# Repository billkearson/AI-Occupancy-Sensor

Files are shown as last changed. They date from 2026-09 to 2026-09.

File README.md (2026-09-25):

# AI Occupancy Sensor

An AI-compatible intelligent room occupancy sensor built around the FireBeetle 2 ESP32-C6, the DFRobot C4002 mmWave presence sensor, the ENS160 air-quality sensor, and the BME280 temperature/humidity/pressure sensor.

Primary program in this repo:

- `AI_Occupancy_Sensor.ino` (main Arduino sketch and active runtime)

`AI_Occupancy_Sensor.md` is the canonical architecture document for the AI Occupancy Sensor project.

## Technology stack

- Hardware: FireBeetle 2 ESP32-C6
- Sensors: DFRobot C4002 mmWave, ENS160, BME280
- Firmware: Arduino sketch in C++
- Connectivity: Wi‑Fi, MQTT, local HTTP server, MCP JSON-RPC over HTTP
- Integration: Home Assistant and Open WebUI via local MQTT/MCP exposure
- Enclosure: 3D-printed case with STL files in the [case](case) folder

## What the current firmware does

- Initializes the I2C bus and the C4002 UART link.
- Polls the C4002, ENS160, and BME280 sensors.
- Fuses the raw readings into a room context that tracks occupancy, motion, occupancy duration, and simple air-quality guidance.
- Runs with sensor degradation tolerance: ENS160 and BME280 failures are logged and tolerated, while the C4002 is required for the node to start.
- Keeps placeholder hooks for MQTT, HTTP, and MCP output so the runtime shape is in place while those interfaces are finished.

## Current code path

- [AI_Occupancy_Sensor.ino](AI_Occupancy_Sensor.ino) is the primary runtime and source of truth for behavior, MCP endpoints, and serial telemetry.
- The sketch owns the sensor polling, context inference, local config loading, and the MCP/HTTP integration points used by the node.

## Shared configuration

The project uses a single shared configuration header for local network and runtime settings: [config.h](config.h).

This file is the source of truth for:

- Wi‑Fi SSID and password
- NTP server list (`NTP_SERVERS`)
- Timezone selection (`TIMEZONE`)
- MQTT broker host, port, username, and password
- MQTT state and availability topic names
- MCP HTTP port (`MCP_HTTP_PORT`)

The Arduino sketch uses this file directly rather than redefining network settings in multiple places.

## Local configuration template

Create a local copy of [config.h.example](config.h.example) named `config.h` and replace each placeholder value before compiling:

- `WIFI_SSID`
- `WIFI_PASSWORD`
- `NTP_SERVERS`
- `TIMEZONE`
- `MCP_HTTP_PORT`
- `MQTT_BROKER_HOST`
- `MQTT_BROKER_PORT`
- `MQTT_USERNAME`
- `MQTT_PASSWORD`
- `MQTT_TOPIC_STATE`
- `MQTT_TOPIC_AVAILABILITY`
- `TEMP_OFFSET_F`
- `HUMIDITY_OFFSET_RH`

Keep the real `config.h` file local to your machine and do not commit credentials to source control.

## Sensor calibration offsets

The BME280 readings can be corrected in `config.h` using these optional offsets:

- `TEMP_OFFSET_F`: Temperature correction in Fahrenheit.
- `HUMIDITY_OFFSET_RH`: Relative humidity correction in RH percentage points.

Temperature offset is entered in Fahrenheit for convenience, then converted internally to Celsius before being applied to sensor values.

Examples:

- If the sensor reads 82.0F and a reference thermometer reads 79.5F, set `TEMP_OFFSET_F = -2.5f`.
- If the sensor reads 39% RH and a reference reads 42% RH, set `HUMIDITY_OFFSET_RH = 3.0f`.

Notes:

- Positive offsets increase reported values; negative offsets decrease them.
- Corrected humidity is clamped to the valid range of 0 to 100% RH.
- Offsets are applied in the current Arduino sketch and any future local port of the same logic.

## Hardware defaults

These defaults are defined in [config.h](config.h):

- Device name: `room-ai-node`
- C4002 UART TX: GPIO 16
- C4002 UART RX: GPIO 17
- C4002 baud rate: `115200`
- I2C SDA: GPIO 19
- I2C SCL: GPIO 20
- I2C clock: `400000`
- MCP HTTP port: `8081`
- MQTT broker host and Wi‑Fi credentials: blank placeholders for local configuration

## Wiring diagram

```mermaid
flowchart LR
    subgraph ESP[FireBeetle 2 ESP32-C6]
        direction TB
        VCC3[3V3]
        GND_TOP[GND]
        SDA[GPIO19 / SDA]
        SCL[GPIO20 / SCL]
        TX[GPIO16 / UART TX]
        RX[GPIO17 / UART RX]
        GND_BOTTOM[GND]
        VCC5[5V]
    end

    ENV[ENS160 + BME280
Combined Environmental Sensor
I²C: SDA / SCL / 3V3 / GND]
    C4002[C4002 mmWave Sensor
UART: RX / TX / GND
5V power tap]

    VCC3 -->|3V3| ENV
    GND_TOP -->|GND| ENV

    SDA -->|I²C SDA| ENV
    SCL -->|I²C SCL| ENV

    TX -->|ESP32 TX -> C4002 RX| C4002
    RX -->|ESP32 RX <- C4002 TX| C4002
    GND_BOTTOM -->|GND| C4002
    VCC5 -->|USB 5V tap| C4002
```

This is the current actual wiring used by the project: the ENS160 and BME280 share the same I²C bus, the C4002 uses the board UART, and the C4002 receives a dedicated 5V tap from the ESP32 USB rail for stable operation.

## Case fasteners

The 3D-printed enclosure uses the following hardware:

- Sensor mounting screws: M2 x 6 mm
- Sensor mounting screws: M2 x 8 mm
- Case assembly hex head bolts: M2 x 12 mm
- Case assembly threaded inserts: M2 x 4 x 3.5 mm

The M2 x 6 mm and M2 x 8 mm screws were used to attach the sensors to the case. The M2 x 12 mm hex head bolts and M2 x 4 x 3.5 mm threaded inserts were used to secure the case panels together.

## Power note for the C4002

The C4002 required more power than the ESP32 board could reliably supply through its GPIO header pins alone. In the current build, the sensor is powered from the ESP32 board's USB 5V rail via a red tap wire visible in the back-case photo. This is a deliberate external power feed for the sensor and is not provided through the ESP32's GPIO pin supply path.

The power tap is a practical hardware workaround to keep the C4002 stable while the ESP32 continues to operate as the controller and local intelligence node.

## Quick start

1. Install the Arduino core for the ESP32-C6 and select the correct board profile in Arduino IDE or VS Code.
2. Copy [config.h.example](config.h.example) to `config.h` and fill in your Wi‑Fi, MQTT, and MCP values.
3. Connect the ESP32-C6 via USB and compile/upload [AI_Occupancy_Sensor.ino](AI_Occupancy_Sensor.ino).
4. Open the serial monitor at 115200 baud to confirm startup logs and sensor readiness.
5. Test the local HTTP endpoints at `http://DEVICE_IP:8081/context` and `http://DEVICE_IP:8081/occupancy/history`, and the MCP endpoint at `http://DEVICE_IP:8081/mcp`.
6. Validate the MCP flow using [MCP-Test.ps1](MCP-Test.ps1) or the examples in [MCP-Testing.md](MCP-Testing.md).

## Troubleshooting

- No serial output: confirm the board profile is set to the ESP32-C6 and USB CDC is enabled.
- C4002 not responding: verify UART wiring and confirm the sensor is receiving stable power from the USB 5V rail as noted in the power section above.
- Wi‑Fi not connecting: verify SSID/password in [config.h](config.h) and check that the board is on the correct network.
- MCP requests failing: use POST with `Content-Type: application/json` and verify the JSON-RPC method names match the runtime implementation.
- Sensor values look wrong: check calibration offsets in [config.h](config.h) and confirm the board and sensor are still physically connected.

## Case build and Open WebUI validation

The repository includes current photos of the case, the printable STL enclosure files, and a screenshot showing live sensor data in Open WebUI.

3D case STL files:

- [case/Case3_front.stl](case/Case3_front.stl) — front panel shell
- [case/Case3_middle.stl](case/Case3_middle.stl) — middle body section
- [case/Case3_back.stl](case/Case3_back.stl) — rear enclosure panel

Case images:

- Front view:

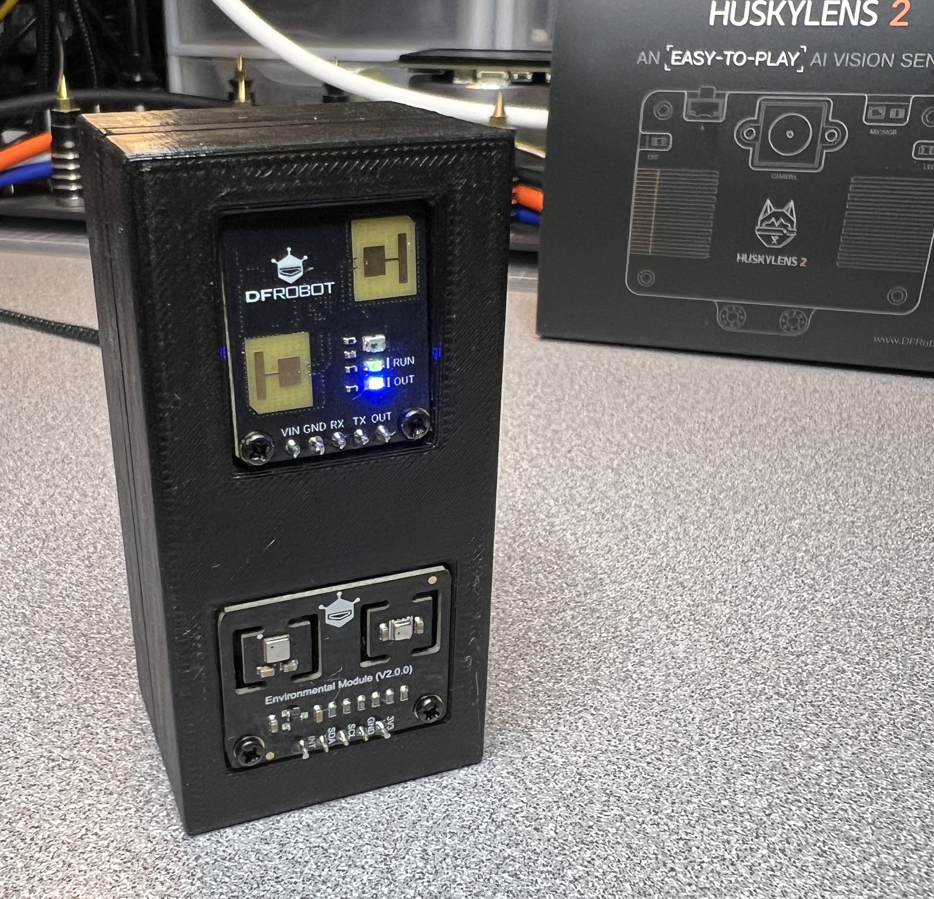
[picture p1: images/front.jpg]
Case front view
	

- Front view (alternate angle):

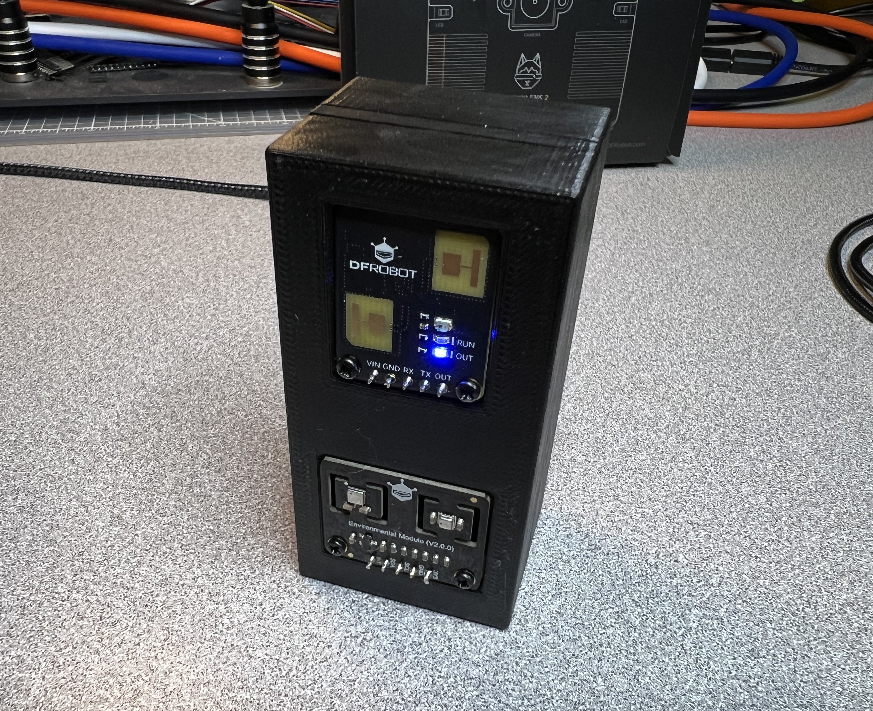
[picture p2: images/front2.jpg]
Alternate front view
	

- Back view:

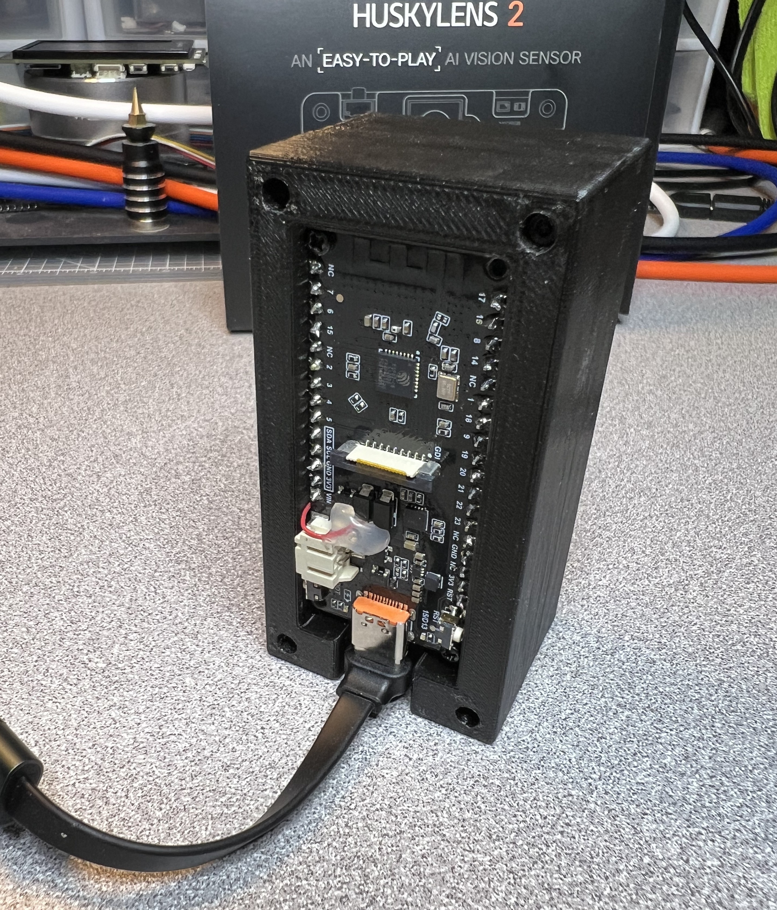
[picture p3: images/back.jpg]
Case back view
	

- Back view (alternate angle):

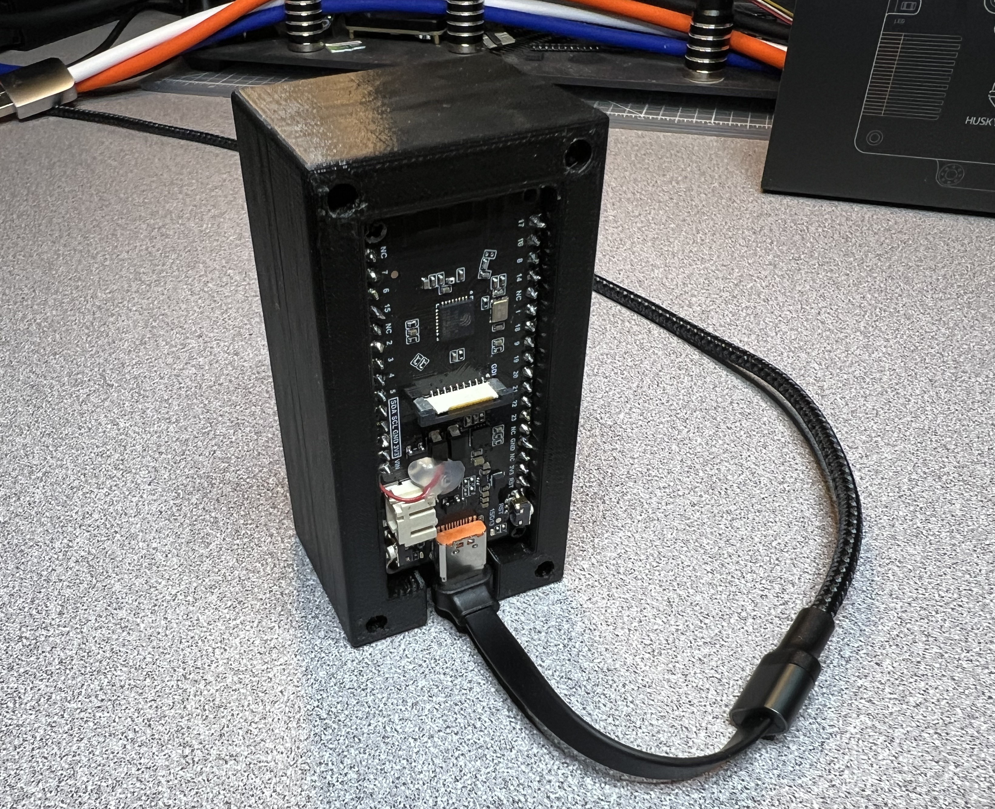
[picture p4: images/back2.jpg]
Alternate back view
	

- Parts and internal layout:

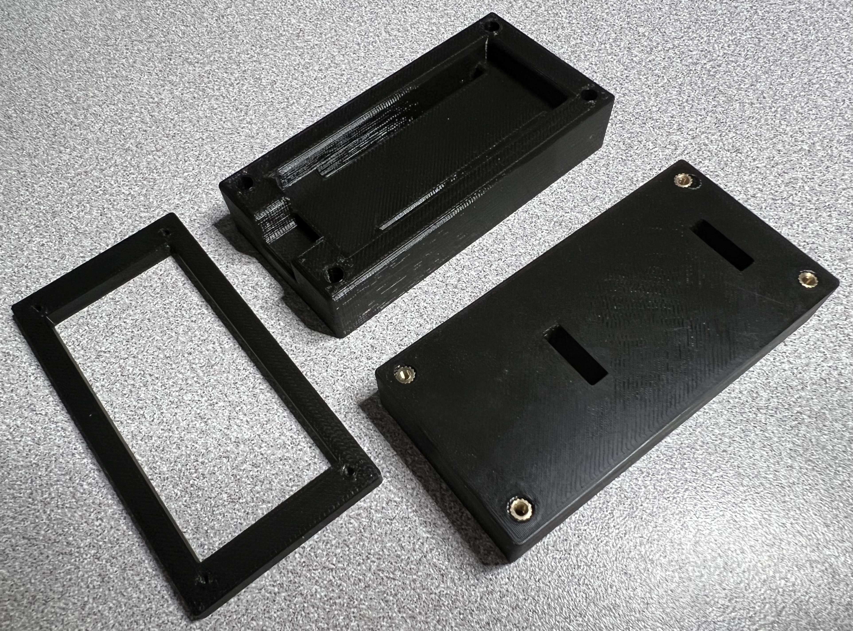
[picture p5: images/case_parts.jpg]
Case parts and internals
	

Open WebUI integration:

- Live sensor view in Open WebUI via MCP:

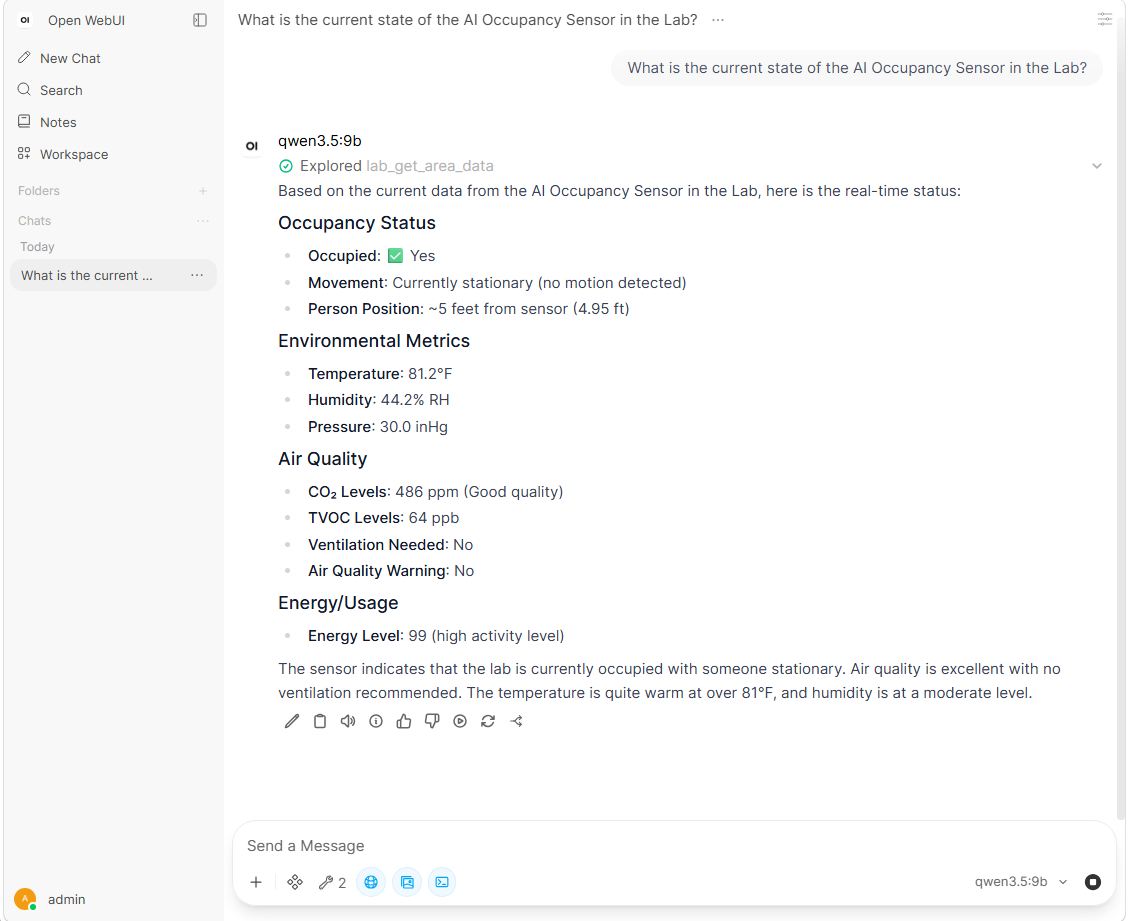
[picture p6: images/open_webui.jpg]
Open WebUI with sensor data
	

Home Assistant integration:

- Live sensor entities and state in Home Assistant:

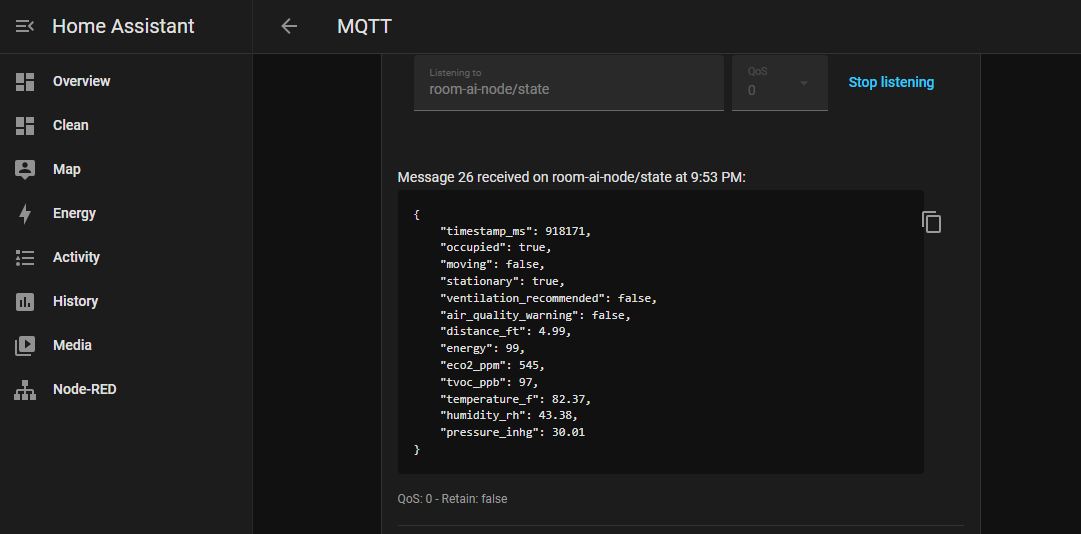
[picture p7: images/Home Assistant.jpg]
Home Assistant sensor view
	

## Console output

The `AI_Occupancy_Sensor.ino` sketch writes startup and loop logs to the serial console at `115200` baud. USB CDC on Boot must be enabled for the ESP32-C6 board profile, and on boards that expose USB CDC you should open the monitor before or immediately after reset so the startup banner is not missed.

Current runtime behavior in the sketch:

- C4002 is polled continuously in the main loop.
- Telemetry is published to serial every 5 seconds.
- Output is grouped with a sample header line.

Current sample format:

```text
--- sample 12 t=2026-09-24T19:51:32-0400 (ntp) ---
occupied=1 moving=0 stationary=1 vent=0
C4002 present=1 motion=0 static=1 dist=5.22ft energy=99
ENS160 ready=1 eco2=552 tvoc=101
BME280 ready=1 temp=82.67F humidity=41.10% pressure=30.04inHg
```

Field notes:

- `occupied`, `moving`, `stationary`, and `vent` are derived context-engine outputs.
- `t=` shows timezone-adjusted wall-clock time when NTP is available, otherwise uptime milliseconds.
- C4002 distance is displayed in feet (`ft`).
- BME280 temperature is displayed in Fahrenheit (`F`).
- BME280 pressure is displayed in inches of mercury (`inHg`).
- C4002 intensity is labeled `energy` (renamed from `activity`).

## Repo layout

- `AI_Occupancy_Sensor.ino` is the main Arduino program.
- `AI_Occupancy_Sensor.md` is the primary architecture and design document.
- `README.md` is the quick-start and operational guide.
- `config.h` and `config.h.example` hold the local network and runtime settings.

## MCP tool contract

Current MCP tool names advertised by tools/list in AI_Occupancy_Sensor.ino:

- get_area_data: Returns real-time environmental and occupancy metrics for the area.
- get_environmental_data: Returns temperature, humidity, and pressure metrics.
- get_occupancy_data: Returns presence, motion, static presence, distance, and energy.
- get_air_quality_data: Returns eCO2 and TVOC metrics.
- get_occupancy_history: Returns bounded occupancy transition history (depth 10).

Current MCP resources advertised by resources/list in AI_Occupancy_Sensor.ino:

- room://context/current: Current room context JSON.
- room://occupancy/history: Occupancy history JSON.

Timestamp contract:

- Payloads now expose `timestamp` (string) instead of `timestamp_ms`.
- When NTP is synced, `timestamp` is timezone-adjusted according to `TIMEZONE` in [config.h](config.h).
- When NTP is not synced, `timestamp` falls back to uptime text (for example, `12345ms`).

Occupancy history behavior:

- History is edge-only: entries are recorded only when `occupied` flips true/false.
- Maximum retained depth is 10 entries.

Tool name change note:

- Previous call names without the `get_` prefix were replaced with the `get_` prefixed names above.
- tools/list and tools/call must use the same canonical names.

MCP session limit note:

- The intended design target is 2 concurrent MCP sessions (`MAX_MCP_SESSIONS = 2`).
- The current Arduino sketch does not yet enforce a real session-cap tracking layer at runtime; this is a design target rather than a live runtime limit.

When tool names or descriptions change, align these locations:

- AI_Occupancy_Sensor.ino: tools/list tool metadata and tools/call routing checks.
- MCP-Test.ps1: JSON-RPC tools/call test payload names.
- MCP-Testing.md: expected tool list and tools/call request examples.
- AI_Occupancy_Sensor.md: MCP tool examples and architectural references.

## Acknowledgement

Special thanks to DFRobot for providing the hardware used in this project as part of their C4002 Free Trial Program.

Kit 3: Multi-Sensor Fusion Kit (Enabling richer environmental sensing)

Included hardware:

- FireBeetle 2 ESP32-C6 x 1 (DFR1075)
- Fermion C4002 mmWave Human Presence Sensor x 1 (SEN0691)
- Fermion ENS160 + BME280 Environmental Sensor x 1 (SEN0335)

## License

This project is licensed under the MIT License. See [LICENSE](LICENSE) for the full text.

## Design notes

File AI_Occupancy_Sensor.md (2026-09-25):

# AI Occupancy Sensor

## ESP32-C6 + C4002 + ENS160 + BME280

This document is the active architecture and reference document for the AI Occupancy Sensor project.

An AI-compatible intelligent room occupancy sensor in which the **FireBeetle 2 ESP32-C6 is the complete edge device**: sensor acquisition, context inference, MQTT integration, Home Assistant discovery, historical resources, and a minimal **MCP Streamable HTTP server** all run directly on the ESP32.

The design intentionally avoids a separate MCP gateway. Every MCP resource and tool is backed by data held by the ESP32.

## Technology stack

- Platform: FireBeetle 2 ESP32-C6
- Firmware: Arduino sketch written in C++
- Sensors: DFRobot C4002 mmWave, ENS160, BME280
- Connectivity: Wi‑Fi, MQTT, HTTP JSON endpoints, MCP Streamable HTTP
- Integration: Home Assistant and Open WebUI
- Enclosure: 3D-printed case using the STL files in the [case](case) folder

---

## 1. Project Goals

The system combines:

* **DFRobot C4002 mmWave Motion & Static Presence**
* **DFRobot ENS160 digital multi-gas sensor**
* **DFRobot BME280 temperature/humidity/pressure sensor**
* **DFRobot FireBeetle 2 ESP32-C6**

The finished node should answer questions such as:

> Is anyone in the room?

> How long has the room been occupied?

> Is the person moving or stationary?

> Is the environmental condition changing?

> Is air quality deteriorating while the room is occupied?

> What changed in the room during the last 30 minutes?

> Why did the system recommend ventilation?

The ESP32 performs deterministic edge inference and exposes the resulting state through:

1. **MQTT**
2. **Home Assistant MQTT Discovery**
3. **HTTP/JSON**
4. **MCP Streamable HTTP**

The architecture is deliberately **local-first**. No cloud service is required.

---

# 2. High-Level Architecture

```mermaid
flowchart LR
    ROOM[Room]

    C4002[C4002 mmWave
Presence + Motion]
    ENS[ENS160
Air quality]
    BME[BME280
Temperature / Humidity / Pressure]

    ESP[FireBeetle 2 ESP32-C6
Sensor Manager
Feature Engine
Context Engine
MQTT + HTTP + MCP]

    HA[Home Assistant]
    MCP[MCP Client / AI Agent]

    ROOM --> C4002
    ROOM --> ENS
    ROOM --> BME

    C4002 -->|UART| ESP
    ENS -->|I²C| ESP
    BME -->|I²C| ESP

    ESP -->|MQTT| HA
    ESP -->|HTTP / JSON| MCP
    ESP -->|MCP Streamable HTTP| MCP
```

The important architectural constraint is:

> **The ESP32 is the source of truth.**

Home Assistant and MCP clients consume the ESP32's state. They do not own the room's resources or intelligence.

---

# 3. Hardware

## 3.1 FireBeetle 2 ESP32-C6

The ESP32-C6 is the central controller.

The ESP32-C6 provides a 32-bit RISC-V processor, Wi-Fi 6, Bluetooth LE, and 802.15.4 connectivity. The current project is implemented as a single Arduino sketch running directly on the board, with the same device responsibilities handled in-code rather than by a separate ESP-IDF app structure.

---

## 3.2 C4002

The C4002 provides the occupancy-related information:

* static presence
* motion
* distance
* target information
* target energy/intensity
* direction where supported by the configured C4002 operating mode

The C4002 communicates with the ESP32 over UART.

### Power note for the C4002

The C4002 needed more power than the ESP32 could reliably provide through its GPIO pin supply path. In the physical build, the sensor is powered from the ESP32 board's USB 5V rail using a visible red tap wire, as seen in the back-case image. This red wire is a deliberate power feed from the board's USB connection and is not a GPIO-supplied power path.

This hardware arrangement was necessary to keep the C4002 stable while the ESP32 continued to act as the local controller, MQTT client, and MCP endpoint host.

---

## 3.3 ENS160

The ENS160 provides:

* TVOC
* eCO₂
* air-quality information

The ENS160 should be treated as an **air-quality/context sensor**, not as a precision CO₂ sensor.

The firmware and API should therefore use the field name:

```text
eco2_ppm
```

rather than:

```text
co2_ppm
```

---

## 3.4 BME280

The BME280 provides:

* temperature
* relative humidity
* atmospheric pressure

The BME280 and ENS160 share the I²C bus.

---

## 3.5 Case Build and Open WebUI Validation

The project now includes real build photos, printable enclosure STL files in the `case/` folder, and an Open WebUI screenshot under `images/`:

### Case hardware fasteners

The 3D-printed enclosure uses the following mounting hardware:

- Sensor mounting screws: M2 x 6 mm
- Sensor mounting screws: M2 x 8 mm
- Case assembly hex head bolts: M2 x 12 mm
- Case assembly threaded inserts: M2 x 4 x 3.5 mm

The M2 x 6 mm and M2 x 8 mm screws were used to attach the sensors to the case. The M2 x 12 mm hex head bolts and M2 x 4 x 3.5 mm threaded inserts were used to secure the case panels together.

### 3D printable case files

- [case/Case3_front.stl](case/Case3_front.stl)
- [case/Case3_middle.stl](case/Case3_middle.stl)
- [case/Case3_back.stl](case/Case3_back.stl)

### Case photos

Front view:

Case front view

Front view (alternate angle):

Alternate front view

Back view:

Case back view

Back view (alternate angle):

Alternate back view

Case parts and internals:

Case parts and internals

### Open WebUI integration screenshot

This screenshot shows the sensor exposed through MCP and consumed in Open WebUI:

Open WebUI with sensor data

### Home Assistant integration screenshot

This screenshot shows the sensor data exposed in Home Assistant:

Home Assistant sensor view

---

## Quick Start

1. Install the ESP32 Arduino board package and choose the FireBeetle 2 ESP32-C6 profile.
2. Copy [config.h.example](config.h.example) to a local [config.h](config.h) and populate Wi‑Fi, MQTT, and MCP settings.
3. Compile and upload [AI_Occupancy_Sensor.ino](AI_Occupancy_Sensor.ino) to the board.
4. Open the serial monitor at 115200 baud to confirm startup logs and sensor initialization.
5. Verify the local HTTP and MCP endpoints on the board's LAN address.
6. Run [MCP-Test.ps1](MCP-Test.ps1) or the examples in [MCP-Testing.md](MCP-Testing.md) to validate MCP behavior.

## Troubleshooting

- The board does not show startup logs: confirm the ESP32-C6 profile and serial monitor settings.
- The C4002 is unstable or silent: verify UART wiring and check the USB 5V power tap used for the sensor.
- MQTT or Wi‑Fi does not connect: review the shared configuration in [config.h](config.h).
- A request to `/context` or `/mcp` fails: confirm the endpoint is being called with the correct HTTP method and JSON-RPC payload.
- Values seem incorrect: check calibration and threshold settings in [config.h](config.h) before testing again.

---

# 4. Actual Wiring

This is the actual hardware wiring currently used in the project.

```mermaid
flowchart LR
    subgraph ESP[FireBeetle 2 ESP32-C6]
        direction TB
        VCC3[3V3]
        GND_TOP[GND]
        SDA[GPIO19 / SDA]
        SCL[GPIO20 / SCL]
        TX[GPIO16 / UART TX]
        RX[GPIO17 / UART RX]
        GND_BOTTOM[GND]
        VCC5[5V]
    end

    ENV[ENS160 + BME280
Combined Environmental Sensor
I²C: SDA / SCL / 3V3 / GND]
    C4002[C4002 mmWave Sensor
UART: RX / TX / GND
5V power tap]

    VCC3 -->|3V3| ENV
    GND_TOP -->|GND| ENV

    SDA -->|I²C SDA| ENV
    SCL -->|I²C SCL| ENV

    TX -->|ESP32 TX -> C4002 RX| C4002
    RX -->|ESP32 RX <- C4002 TX| C4002
    GND_BOTTOM -->|GND| C4002
    VCC5 -->|USB 5V tap| C4002
```

The board uses the FireBeetle 2 ESP32-C6 I²C pins `GPIO19` (SDA) and `GPIO20` (SCL). The default UART mapping for the C4002 is `GPIO16` as TX and `GPIO17` as RX. These values are defined in the firmware and kept in a single configuration location rather than being scattered across the code.

Network settings are centralized in the shared [config.h](config.h) file. This includes Wi‑Fi, MQTT broker details, and the MCP HTTP port so the project has a single source of truth instead of duplicate values in multiple files.

Time settings are also centralized in [config.h](config.h), including comma-delimited NTP servers (`NTP_SERVERS`) and timezone selection (`TIMEZONE`). If timezone parsing is unavailable, the runtime falls back to UTC.

## Acknowledgement

Special thanks to DFRobot for providing the hardware used in this project as part of their C4002 Free Trial Program, in Kit 3: Multi-Sensor Fusion Kit (Enabling richer environmental sensing).

Included hardware:

- FireBeetle 2 ESP32-C6 x 1 (DFR1075)
- Fermion C4002 mmWave Human Presence Sensor x 1 (SEN0691)
- Fermion ENS160 + BME280 Environmental Sensor x 1 (SEN0335)

## License

This project is licensed under the MIT License. See [LICENSE](LICENSE) for the full text.

The repository also includes [config.h.example](config.h.example), which is the template to copy locally as `config.h` and populate with your environment-specific values before building or flashing.

Verify the C4002 module's power and logic-level requirements before connecting it directly to 3.3 V GPIO.

---

# 5. Software Architecture

The primary runtime is the single-file Arduino sketch:

```text
AI_Occupancy_Sensor.ino
├── Configuration include
│   └── config.h
├── Sensor drivers (in-sketch classes)
│   ├── C4002Driver (UART occupancy/presence)
│   ├── Ens160Driver (I2C air quality)
│   └── Bme280Driver (I2C temperature/humidity/pressure)
├── Data models
│   ├── SensorSnapshot
│   └── RoomContext
├── Context inference
│   └── ContextEngine update and state tracking
├── Integrations
│   ├── MQTT publish and discovery payloads
│   ├── HTTP endpoints
│   └── MCP Streamable HTTP resources/tools
└── Main loop orchestration
  ├── Sensor polling
  ├── Context update
  ├── Telemetry/log output
  └── MCP/HTTP request handling
```

The current repository is intentionally Arduino-first and does not keep a separate ESP-IDF app tree as the active code path. The architecture remains modular in design, but the actual runtime is the single-file sketch that directly owns the sensor drivers, inference engine, and network integrations.

---

# 6. Runtime Tasks

Use FreeRTOS tasks to keep sensor acquisition independent from network activity.

```mermaid
flowchart TD
    ESP[ESP32-C6]

    C4002[C4002 Task
Radar state]
    ENV[Environment Task
Env state]
    NET[Network Task]

    FE[Feature Engine]
    CE[Context Engine]
    EE[Event Engine]
    MQTT[MQTT]
    HIST[History]
    HTTP[MCP / HTTP]

    ESP --> C4002
    ESP --> ENV
    ESP --> NET

    C4002 --> FE
    ENV --> FE
    FE --> CE
    CE --> EE

    EE --> MQTT
    EE --> HIST
    EE --> HTTP
```

Recommended starting rates:

| Function | Rate |
| --- | ---: |
| C4002 acquisition | 5–10 Hz |
| BME280 | 1 Hz |
| ENS160 | 1 Hz |
| Feature calculation | 1 Hz |
| Context engine | 1 Hz |
| MQTT telemetry |  1–5 seconds |
| MQTT state | On change |
| MCP state | On request |
| MCP events | Event-driven |

Current Arduino sketch behavior (`AI_Occupancy_Sensor.ino`) differs slightly for debug visibility:

- C4002 UART notifications are polled continuously.
- Combined telemetry is printed every 5 seconds.
- Sample `t=` prints timezone-adjusted wall-clock time when NTP is synced, otherwise uptime milliseconds.
- Console display uses feet (`ft`), Fahrenheit (`F`), and inches of mercury (`inHg`).

Current occupancy history behavior in the sketch:

- Depth is bounded to 10 entries.
- Entries are edge-only and recorded only when `occupied` flips true/false.

---

# 7. Canonical Room Observation

All sensor libraries should feed a normalized internal structure.

```cpp
struct RoomObservation {
  const char* timestamp;
  bool time_source_ntp;

    // Environment
    float temperature_c;
    float humidity_pct;
    float pressure_hpa;

    // Air quality
    uint16_t tvoc_ppb;
    uint16_t eco2_ppm;
    uint8_t aqi;

    // Radar
    bool presence;
    bool motion;
    float target_distance_m;
    uint8_t target_energy;
    float target_speed;
    int8_t target_direction;
    uint8_t target_count;

    // Radar/environment information
    float light_level;

    // Derived values
    float activity_score;
    float presence_confidence;
    float temperature_trend;
    float humidity_trend;
    float eco2_trend;
    float tvoc_trend;
};
```

Everything else should derive from this structure.

---

# 8. Feature Engine

Raw sensor values are converted into temporal features.

```text
presence_duration
absence_duration
motion_rate
stationary_duration

temperature_delta_5m
humidity_delta_5m

eco2_delta_5m
tvoc_delta_5m

activity_score
presence_confidence

air_quality_trend
environmental_anomaly_score
```

The system should maintain short rolling windows rather than storing every raw sample indefinitely.

Suggested windows:

```text
10 seconds
1 minute
5 minutes
15 minutes
1 hour
24 hours
```

---

# 9. Context Engine

The first version should use a deterministic state machine.

Do **not** make an LLM responsible for basic occupancy inference.

```text
                 ┌─────────────┐
                 │    EMPTY    │
                 └──────┬──────┘
                        │
                    presence
                        │
                        ▼
                 ┌─────────────┐
                 │  OCCUPIED   │
                 └──────┬──────┘
                        │
             ┌──────────┼──────────┐
             │          │          │
             ▼          ▼          ▼
          ACTIVE     STATIONARY  TRANSITION
             │          │
             │          ▼
             │     LONG_STATIONARY
             │          │
             └────┬─────┘
                  ▼
            ENVIRONMENTAL
               CONTEXT
```

Initial states:

```text
EMPTY
OCCUPIED
ACTIVE
STATIONARY
LONG_STATIONARY
AIR_DEGRADING
HOT
HUMID
VENTILATION_RECOMMENDED
ENVIRONMENTAL_ANOMALY
```

---

# 10. Confidence Rather Than Absolute Claims

The system should never pretend that the sensors know more than they actually do.

Use:

```json
{
  "state": "stationary",
  "confidence": 0.91
}
```

rather than:

```json
{
  "person_is_working": true
}
```

Higher-level interpretations can be represented as hypotheses:

```json
{
  "context": "work_like_stationary_activity",
  "confidence": 0.78
}
```

The distinction is important because mmWave presence plus environmental measurements cannot reliably determine a person's exact activity.

---

# 11. Canonical Room State

The ESP32 maintains one current room state.

```json
{
  "schema": "roomai.v1",

  "device": {
    "id": "roomai-01",
    "room": "office",
    "firmware": "0.1.0"
  },

  "presence": {
    "present": true,
    "confidence": 0.97,
    "duration_s": 4230,
    "motion": false,
    "distance_m": 2.14
  },

  "activity": {
    "state": "stationary",
    "score": 0.17,
    "confidence": 0.88
  },

  "environment": {
    "temperature_c": 24.3,
    "humidity_pct": 48.2,
    "pressure_hpa": 1014.1
  },

  "air": {
    "eco2_ppm": 812,
    "tvoc_ppb": 193,
    "aqi": 1
  },

  "context": {
    "room_state": "occupied",
    "air_state": "good",
    "ventilation_recommended": false
  }
}
```

This structure is the foundation for MQTT, Home Assistant, HTTP, and MCP.

---

# 12. Local History

Because **all resources must live on the ESP32**, the device needs a local history mechanism.

Do not attempt to retain every high-frequency sensor reading forever.

Instead, maintain:

### Short-term raw history

```text
10 Hz radar-derived observations
approximately 1–5 minutes
```

### 1-second/1-minute aggregates

```text
temperature
humidity
pressure
TVOC
eCO₂
presence
motion
activity
```

### Event history

Store important events for a much longer period:

```text
presence_started
presence_ended
activity_changed
air_quality_degrading
ventilation_recommended
environmental_anomaly
temperature_threshold
humidity_threshold
sensor_error
```

Use a circular buffer.

For longer persistence, periodically write compact aggregate/event records to NVS or a dedicated flash partition.

Avoid writing every sensor sample to flash because flash endurance is finite.

---

# 13. MQTT Architecture

MQTT remains the Home Assistant integration layer.

Use:

```text
roomai/<room>/
```

Example:

```text
roomai/office/state
roomai/office/telemetry
roomai/office/event
roomai/office/availability

roomai/office/command/recalibrate
roomai/office/command/reset
roomai/office/command/set_config
```

---

# 14. MQTT State

Example:

```json
{
  "state": "stationary",
  "presence": true,
  "presence_confidence": 0.96,
  "activity": "low",
  "activity_confidence": 0.87,
  "air_quality": "good",
  "ventilation_recommended": false
}
```

Publish this when the state changes.

---

# 15. MQTT Telemetry

Example:

```json
{
  "ts": 1786560000,
  "temperature_c": 24.3,
  "humidity_pct": 47.8,
  "pressure_hpa": 1014.2,
  "tvoc_ppb": 182,
  "eco2_ppm": 684,
  "aqi": 1,
  "presence": true,
  "motion": false,
  "distance_m": 2.14,
  "activity_score": 0.17
}
```

Telemetry can be published periodically.

---

# 16. MQTT Events

Example:

```json
{
  "event": "ventilation_recommended",
  "severity": "warning",
  "confidence": 0.89,
  "duration_occupied_s": 5400,
  "eco2_trend_ppm_min": 4.7,
  "tvoc_trend_ppb_min": 1.8
}
```

Events should be published immediately.

---

# 17. Home Assistant

Use MQTT Discovery so the ESP32 presents itself as a single device containing multiple entities.

Expose:

### Binary sensors

```text
Room Presence
Room Motion
Ventilation Recommended
Environmental Anomaly
```

### Sensors

```text
Temperature
Humidity
Pressure
eCO₂
TVOC
AQI
Target Distance
Activity Score
Presence Confidence
```

### Diagnostic entities

```text
Wi-Fi RSSI
MQTT Connected
Firmware Version
Uptime
Free Heap
Sensor Status
```

### State entities

```text
Room State
Activity State
Air Quality State
```

Home Assistant's MQTT integration supports device discovery and multiple MQTT components grouped under a device. ([Espressif Systems][2])

---

# 18. ESP32 HTTP API

The ESP32 should expose a small normal HTTP API in addition to MCP.

```text
GET /api/v1/status
GET /api/v1/state
GET /api/v1/telemetry
GET /api/v1/events
GET /api/v1/history
GET /api/v1/health

POST /api/v1/command/recalibrate
POST /api/v1/command/reset
```

This API is useful for:

* debugging
* firmware development
* Home Assistant integrations
* curl
* browser testing
* MCP implementation
* diagnostics

ESP-IDF provides a lightweight HTTP server with URI handlers and persistent connection support. ([Espressif Systems][3])

---

# 19. MCP Design

## Principle

The MCP implementation should be **minimal**.

The ESP32 does not need a general-purpose MCP framework.

Implement only the MCP protocol features required by this application:

```text
initialize
tools/list
tools/call
resources/list
resources/read
```

Optionally support:

```text
notifications
```

for event streaming.

Do not implement:

```text
prompts
sampling
elicitation
roots
tasks
```

unless a later requirement makes them necessary.

---

# 20. MCP Transport

Use **Streamable HTTP**.

The MCP endpoint is:

```text
POST /mcp
GET  /mcp
```

The current MCP transport specification defines Streamable HTTP around a single MCP endpoint supporting POST and GET, with server-to-client streaming available through SSE. ([Espressif Systems][2])

The implementation should use:

```text
Content-Type: application/json
```

for ordinary JSON responses and:

```text
Content-Type: text/event-stream
```

when an MCP response needs to stream.

Do not implement the older standalone HTTP+SSE transport.

---

# 21. Minimal MCP JSON-RPC Layer

MCP messages are JSON-RPC 2.0.

The minimum request structure is:

```json
{
  "jsonrpc": "2.0",
  "id": 1,
  "method": "tools/list",
  "params": {}
}
```

Response:

```json
{
  "jsonrpc": "2.0",
  "id": 1,
  "result": {
    "tools": []
  }
}
```

The ESP32 implementation should use a small JSON parser and avoid dynamic allocation where possible.

---

# 22. MCP Initialization

The server should respond to:

```text
initialize
```

with its supported protocol version and capabilities.

Conceptually:

```json
{
  "jsonrpc": "2.0",
  "id": 1,
  "result": {
    "protocolVersion": "<supported-version>",
    "capabilities": {
      "resources": {},
      "tools": {}
    },
    "serverInfo": {
      "name": "roomai-esp32",
      "version": "0.1.0"
    }
  }
}
```

The exact protocol version should be a firmware configuration constant and updated as the MCP specification evolves.

---

# 23. Active MCP Tools

The current Arduino implementation exposes these MCP tools:

* `get_area_data`
* `get_environmental_data`
* `get_occupancy_data`
* `get_air_quality_data`
* `get_occupancy_history`

These tool names are the canonical names used by the sketch, the PowerShell validation script, and the markdown test guide.

The active implementation in AI_Occupancy_Sensor.ino returns structured JSON payloads and a text payload for each tool call, and it validates the tool name against the current list before executing.

---

# 24. Active MCP Resource

The current implementation exposes the following MCP resource URIs:

```text
room://context/current
room://occupancy/history
```

`room://context/current` returns the latest room context in JSON form.

`room://occupancy/history` returns bounded edge-only occupancy transition history (depth 10).

---
# 25. MCP Streaming

Streaming should be minimal and event-driven.

A client can issue:

```text
GET /mcp
```

with an MCP-compatible request for an SSE stream.

The ESP32 maintains a small list of connected stream clients.

When a significant room event occurs:

```text
presence_started
presence_ended
activity_changed
air_quality_degrading
ventilation_recommended
environmental_anomaly
sensor_error
```

the event is serialized as an MCP notification.

Conceptually:

```text
ESP32
  │
  ├── Context Engine
  │       │
  │       ▼
  │    Event Queue
  │       │
  │       ▼
  │    MCP Stream
  │       │
  │       ▼
  │    AI Client
```

Do not stream every BME280 or ENS160 reading.

Stream **meaningful state changes**.

---

# 26. MCP Session Management

For the minimum implementation:

* support one or a small configurable number of concurrent MCP sessions
* assign a session identifier when required by the negotiated transport
* bound session lifetime
* clean up disconnected clients
* keep per-session memory small

Do not allocate a large object graph for each connection.

A fixed session pool is preferable:

```cpp
struct McpSession {
    bool active;
    uint32_t id;
    int socket;
    uint32_t last_activity;
};
```

For a constrained embedded implementation, something like:

```text
MAX_MCP_SESSIONS = 2
```

is a reasonable starting point.

Important note: the current Arduino implementation does not yet enforce an active session pool or track a real MCP session count at runtime; this value is the intended design limit, not a currently enforced runtime cap.

---

# 27. HTTP Server Resource Limits

The ESP-IDF HTTP server is designed as a lightweight embedded server and supports URI handlers and configurable server resources. ([Espressif Systems][3])

Configure conservatively.

Example starting point:

```text
max URI handlers:       small
max open sockets:       4–6
MCP sessions:           2
HTTP request size:      bounded
JSON payload size:      bounded
history response:       bounded
```

The exact values should be tuned after measuring heap usage on the actual firmware.

---

# 28. Memory Strategy

The ESP32-C6 has limited embedded memory, so avoid unnecessary dynamic allocation.

Prefer:

```text
static buffers
fixed-size arrays
ring buffers
bounded JSON
fixed MCP sessions
fixed event queue
```

Avoid:

```text
unbounded history
large JSON documents
full MQTT payload retention
large HTTP request bodies
unbounded SSE connections
```

The goal is for the MCP server to be just another small HTTP handler, not a large framework.

---

# 29. Data Flow

## Sensor → Context

```text
C4002
   ↓
Radar observation

ENS160
   ↓
Air observation

BME280
   ↓
Environment observation

         ↓

Normalized RoomObservation

         ↓

Feature Engine

         ↓

Context Engine

         ↓

RoomState + Events
```

## RoomState → MQTT

```text
RoomState
    ↓
MQTT publisher
    ↓
Home Assistant
```

## RoomState → MCP

```text
RoomState
    ↓
MCP resource handler
    ↓
JSON-RPC response
    ↓
MCP client / AI
```

## Event → MCP stream

```text
Context Engine
      ↓
Event
      ↓
Event Queue
      ↓
MCP Stream
      ↓
AI client
```

---

# 30. Example AI Interaction

An MCP client asks:

> What's happening in the office?

The client can request:

```text
room://current
room://environment
room://events
```

The ESP32 returns:

```text
Presence: true
Presence confidence: 97%
Duration: 71 minutes
Activity: stationary
Temperature: 74°F
Humidity: 48%
eCO₂: 812 ppm
TVOC: 193 ppb

Recent event:
air_quality_degrading
```

The AI can then reason:

> The room is occupied and the occupant has been relatively stationary for about an hour. Temperature and humidity are stable, while eCO₂ has been trending upward. The system has therefore flagged ventilation as potentially useful.

The AI isn't responsible for measuring or storing the room.

It is simply reasoning over the ESP32's local resources.

---

# 31. Example "Why?" Interaction

MCP tool:

```text
get_occupancy_history
```

can return:

```text
occupied state transitions
```

```text
Presence:
71 minutes

eCO₂:
620 → 812 ppm

TVOC:
121 → 193 ppb

Temperature:
23.7 → 24.3 °C

Humidity:
46 → 48 %
```

The AI can infer:

```text
Occupied
+
eCO₂ rising
+
TVOC rising
+
long occupancy
=
ventilation recommendation
```

The important point is that the **evidence originates on the ESP32**.

---

# 32. MQTT and MCP Are Independent

The system should continue operating if either integration disappears.

### MQTT unavailable

The ESP32 continues:

```text
sensor acquisition
context inference
local history
HTTP
MCP
```

### MCP client unavailable

The ESP32 continues:

```text
sensor acquisition
context inference
MQTT
Home Assistant
local history
```

### Home Assistant unavailable

The ESP32 continues to function independently.

This makes the room node autonomous.

---

# 33. Local-First Failure Model

```text
                    ESP32-C6
                       │
          ┌────────────┼─────────────┐
          │            │             │
       Sensors       History      Context
          │            │             │
          └────────────┼─────────────┘
                       │
                ┌──────┴───────┐
                │              │
              MQTT            MCP
                │              │
          optional          optional
```

No cloud dependency exists in the core architecture.

---

# 34. Security

Do not expose the ESP32 MCP endpoint directly to the public Internet.

Recommended:

```text
Internet
    X
    │
    │ no port forwarding
    ▼
Local LAN
    │
    ├── Home Assistant
    ├── MQTT broker
    └── MCP client
           │
           ▼
       ESP32-C6
```

For local deployment, authenticate the MCP endpoint and validate the expected host/origin behavior appropriate to the deployment.

The MCP specification calls out DNS-rebinding protection and recommends validating the `Origin` header and implementing authentication for Streamable HTTP servers. ([Espressif Systems][2])

At minimum:

```text
LAN-only
+
authentication
+
bounded connections
+
no Internet exposure
```

For a higher-security installation, use HTTPS/TLS as supported by ESP-IDF and provision device certificates.

---

# 35. OTA

Firmware should eventually support OTA.

The firmware update should replace:

```text
sensor drivers
context engine
MQTT
HTTP
MCP
```

as one atomic firmware image.

Do not make the MCP protocol implementation independently updatable.

---

# 36. Configuration

Store configuration in NVS.

Example:

```json
{
  "device_id": "roomai-01",
  "room": "office",

  "wifi": {
    "ssid": "...",
    "password": "..."
  },

  "mqtt": {
    "host": "192.168.1.10",
    "port": 1883,
    "username": "...",
    "password": "..."
  },

  "context": {
    "absence_timeout_s": 300,
    "stationary_timeout_s": 600,
    "ventilation_delay_s": 300
  },

  "mcp": {
    "enabled": true,
    "max_sessions": 2
  }
}
```

Credentials should not be exposed through the public MCP resources.

`room://config` should return only safe configuration:

```json
{
  "room": "office",
  "absence_timeout_s": 300,
  "stationary_timeout_s": 600,
  "mcp_enabled": true
}
```

Never return Wi-Fi or MQTT passwords.

---

# 37. Implementation Notes

The current codebase is intentionally organized as a single Arduino sketch rather than a separate ESP-IDF application tree. The design still preserves clear boundaries for sensor drivers, state inference, and integration logic, but these are implemented directly in the sketch instead of being split into an external ESP-IDF component layout.

The DFRobot sensor libraries can still be wrapped behind the project's own sensor interfaces for future refactoring or porting work.

---

# 38. Recommended Interfaces

Keep the application independent of specific sensor libraries.

```cpp
class RadarSensor {
public:
    virtual bool begin() = 0;
    virtual bool update(RadarObservation& observation) = 0;
};

class AirSensor {
public:
    virtual bool begin() = 0;
    virtual bool update(AirObservation& observation) = 0;
};

class EnvironmentSensor {
public:
    virtual bool begin() = 0;
    virtual bool update(EnvironmentObservation& observation) = 0;
};
```

Then:

```text
DFRobot C4002
      ↓
RadarSensor

DFRobot ENS160
      ↓
AirSensor

DFRobot BME280
      ↓
EnvironmentSensor
```

This prevents the rest of the application from becoming coupled to vendor APIs.

---

# 39. Context Engine API

The context engine can have a simple interface:

```cpp
class ContextEngine {
public:
    void update(const RoomObservation& observation);

    const RoomState& state() const;

    bool hasNewEvent() const;

    bool popEvent(RoomEvent& event);
};
```

The MQTT and MCP layers both consume the resulting `RoomState`.

---

# 40. MCP Server API

The embedded MCP implementation can remain similarly small:

```cpp
class McpServer {
public:
    void begin(httpd_handle_t server);

    esp_err_t handlePost(httpd_req_t* request);
    esp_err_t handleGet(httpd_req_t* request);

private:
    void handleInitialize(...);
    void handleToolsList(...);
    void handleToolsCall(...);
    void handleResourcesList(...);
    void handleResourcesRead(...);
};
```

The server should call application functions rather than directly accessing sensor drivers.

For example:

```text
MCP
 │
 ▼
RoomState
 │
 ├── ContextEngine
 ├── History
 └── EventQueue
```

not:

```text
MCP
 │
 ├── C4002
 ├── ENS160
 └── BME280
```

MCP should consume **room information**, not raw hardware interfaces.

---

# 41. Minimum MCP Request Routing

The implementation can use a simple dispatcher:

```text
POST /mcp
     │
     ▼
Parse JSON-RPC
     │
     ├── initialize
     │
     ├── tools/list
     │
     ├── tools/call
     │
     ├── resources/list
     │
     └── resources/read
```

Unknown methods return the appropriate JSON-RPC/MCP error.

This keeps the embedded implementation small.

---

# 42. Active MCP Tool Routing

```text
tools/call
     │
     ├── get_area_data
     │        ↓
     │    current room context JSON
     │
     ├── get_environmental_data
     │        ↓
     │    temperature / humidity / pressure
     │
     ├── get_occupancy_data
     │        ↓
     │    presence / motion / static / distance / energy
     │
     ├── get_air_quality_data
     │        ↓
     │    eCO₂ / TVOC
     │
     └── get_occupancy_history
          ↓
        edge-only occupancy transition history (depth 10)
```

This matches the tool names currently implemented in AI_Occupancy_Sensor.ino.

---

# 43. Active Resource Routing

```text
resources/read
       │
    ├── room://context/current
    │        ↓
    │   current room context JSON
    │
    └── room://occupancy/history
       ↓
     edge-only occupancy transition history JSON
```

This is the live MCP resource implemented by the current sketch.

---

# 44. What the ESP32 Should NOT Do

The ESP32 should not attempt to:

* run an LLM
* maintain an unlimited database
* store years of raw telemetry
* proxy arbitrary Internet requests
* implement every MCP capability
* expose arbitrary filesystem access
* execute arbitrary code requested through MCP
* let an AI directly manipulate GPIO without explicit application-level authorization

The ESP32 should remain a **bounded, deterministic room intelligence appliance**.

---

# 45. What the AI Should Do

The AI/client should handle:

* natural-language questions
* correlation between resources
* explanations
* summarization
* higher-level reasoning
* natural-language recommendations
* cross-room reasoning if multiple nodes are available

Example:

```text
ESP32:
"eCO₂ increased 31% during occupancy."

AI:
"The room has been occupied for approximately two hours and
eCO₂ has steadily increased. Ventilation may be beneficial."
```

---

# 46. Multiple Rooms

The architecture scales naturally.

Each room gets its own ESP32:

```text
roomai-office
roomai-bedroom
roomai-kitchen
roomai-living
```

Each has:

```text
own sensors
own state
own history
own MQTT topics
own MCP endpoint
```

An MCP client can connect to each device separately.

Alternatively, a future local MCP aggregator could be added without changing the individual room nodes.

The important point is that **the room node itself remains complete**.

---

# 47. Example Final Deployment

```text
                       HOME LAN
                           │
       ┌───────────────────┼───────────────────┐
       │                   │                   │
       ▼                   ▼                   ▼
 ┌─────────────┐     ┌─────────────┐     ┌─────────────┐
 │ Office ESP  │     │ Bedroom ESP │     │ Kitchen ESP │
 │             │     │             │     │             │
 │ C4002       │     │ C4002       │     │ C4002       │
 │ ENS160      │     │ ENS160      │     │ ENS160      │
 │ BME280      │     │ BME280      │     │ BME280      │
 │             │     │             │     │             │
 │ MQTT        │     │ MQTT        │     │ MQTT        │
 │ MCP/HTTP    │     │ MCP/HTTP    │     │ MCP/HTTP    │
 └──────┬──────┘     └──────┬──────┘     └──────┬──────┘
        │                   │                   │
        └───────────────────┼───────────────────┘
                            │
                     ┌──────▼──────┐
                     │    MQTT     │
                     │   Broker    │
                     └──────┬──────┘
                            │
                     ┌──────▼──────┐
                     │    Home     │
                     │  Assistant  │
                     └─────────────┘

AI Client
    │
    ├──── MCP → Office ESP
    ├──── MCP → Bedroom ESP
    └──── MCP → Kitchen ESP
```

---

# 48. Near-Term Priorities

```text
sensor_error
```

Everything else can wait.

---

# 49. Final Architecture

The resulting device is essentially a self-contained **AI-readable room sensor**:

```text
┌──────────────────────────────────────────────────────┐
│                    ESP32-C6 ROOM AI                  │
│                                                      │
│  ┌────────┐   ┌────────┐   ┌────────┐                │
│  │ C4002  │   │ ENS160 │   │ BME280 │                │
│  └───┬────┘   └───┬────┘   └───┬────┘                │
│      │            │            │                     │
│      └────────────┼────────────┘                     │
│                   ▼                                  │
│          ┌─────────────────┐                         │
│          │ Sensor Manager  │                         │
│          └────────┬────────┘                         │
│                   ▼                                  │
│          ┌─────────────────┐                         │
│          │ Feature Engine  │                         │
│          └────────┬────────┘                         │
│                   ▼                                  │
│          ┌─────────────────┐                         │
│          │ Context Engine  │                         │
│          └────────┬────────┘                         │
│                   ▼                                  │
│          ┌─────────────────┐                         │
│          │ Room State      │                         │
│          │ Event History   │                         │
│          │ Local History   │                         │
│          └───────┬─┬───────┘                         │
│                  │ │                                 │
│          ┌───────┘ └────────┐                        │
│          ▼                  ▼                        │
│       MQTT                MCP/HTTP                   │
│          │                  │                        │
└──────────┼──────────────────┼────────────────────────┘
           │                  │
           ▼                  ▼
     Home Assistant       AI / MCP Client
```

The central design rule is:

> **Sense locally. Infer locally. Store locally. Expose locally.**

MQTT makes the node useful to Home Assistant.

The minimal Streamable HTTP MCP server makes the same node directly understandable to an AI client.

And because the **resources, history, events, context state, and sensor data all live on the ESP32**, the MCP interface remains a thin protocol layer over the device's existing room-intelligence model rather than introducing another backend.

### References

* [MCP specification — Streamable HTTP transport] [MCP Streamable HTTP specification](https://modelcontextprotocol.io/specification/2025-06-18/basic/transports?utm_source=chatgpt.com)
* [ESP-IDF ESP32-C6 documentation] [ESP32-C6 ESP-IDF documentation](https://docs.espressif.com/projects/esp-idf/en/stable/esp32c6/?utm_source=chatgpt.com)
* [ESP-IDF HTTP Server] [ESP-IDF HTTP Server documentation](https://docs.espressif.com/projects/esp-idf/en/stable/esp32c6/api-reference/protocols/esp_http_server.html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)
* [Home Assistant MQTT integration] [Home Assistant MQTT documentation](https://www.home-assistant.io/integrations/mqtt/?utm_source=chatgpt.com)

[1]: https://docs.espressif.com/projects/esp-idf/en/stable/esp32c6/get-started/index.html?utm_source=chatgpt.com "Get Started - ESP32-C6 - — ESP-IDF Programming Guide v6.0.2 documentation"
[2]: https://docs.espressif.com/projects/esp-idf/en/v3.3.3/api-reference/protocols/esp_http_server.html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 "HTTP Server — ESP-IDF Programming Guide v3.3.3 documentation"
[3]: https://docs.espressif.com/projects/esp-idf/en/stable/esp32c6/api-reference/protocols/index.html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 "Application Protocols - ESP32-C6 - — ESP-IDF Programming Guide v6.0.2 documentation"

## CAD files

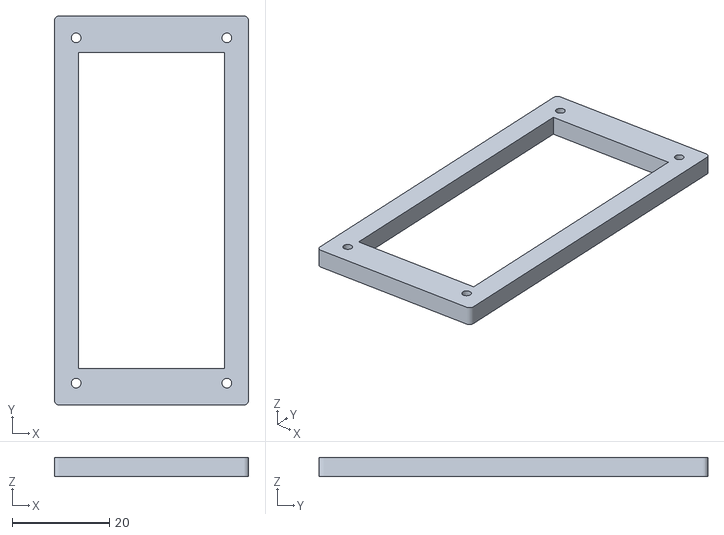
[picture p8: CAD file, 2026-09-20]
case/Case3_middle.stl
40.0 x 80.0 x 4.00

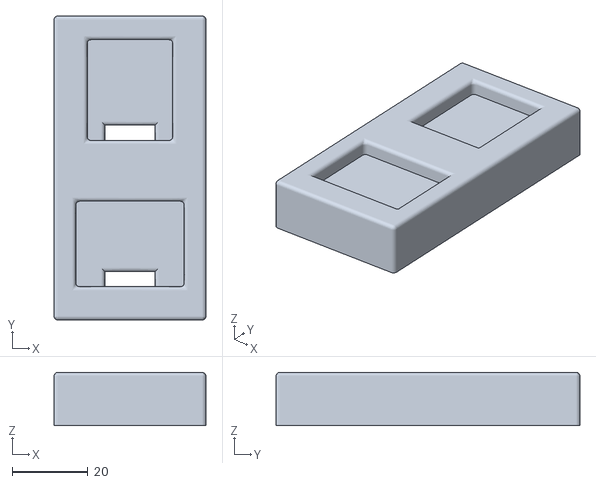
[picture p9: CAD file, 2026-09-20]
case/Case3_front.stl
40.0 x 80.0 x 14.0

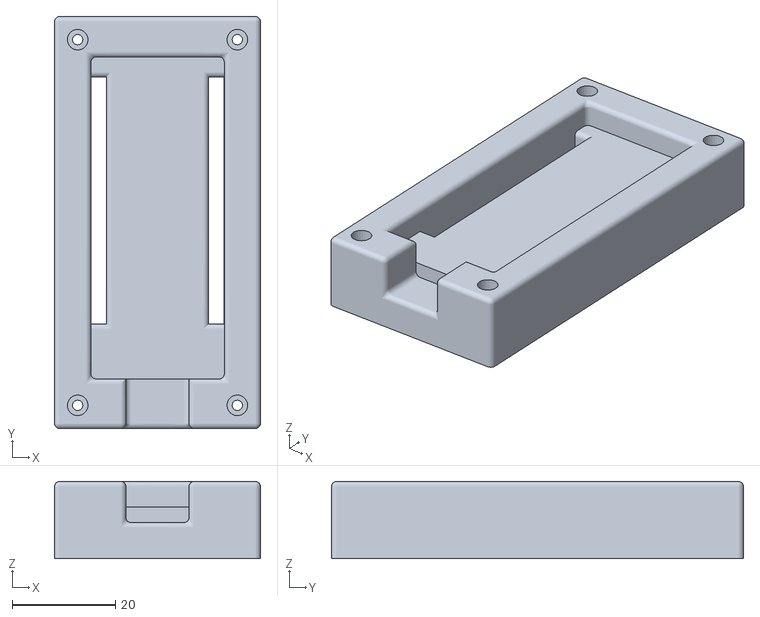
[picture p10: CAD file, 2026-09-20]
case/Case3_back.stl
40.0 x 80.0 x 15.0

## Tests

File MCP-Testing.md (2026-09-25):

# MCP Server Testing Guide (Arduino Sketch)

This guide tests the MCP HTTP endpoints implemented in AI_Occupancy_Sensor.ino.

## Prerequisites

- ESP32-C6 flashed with the current AI_Occupancy_Sensor.ino sketch.
- Serial Monitor open at 115200 baud.
- Your computer is on the same local network as the ESP32.
- Copy [config.h.example](config.h.example) to a local `config.h` and fill in your values before flashing.
- Wi‑Fi credentials, MQTT settings, and the MCP HTTP port are configured in [config.h](config.h). They should not be duplicated in the sketch itself.

## 1. Confirm MCP server startup

After boot, confirm a log line like:

```text
MCP HTTP ready: http://DEVICE_IP:8081/mcp
```

Use that DEVICE_IP in all commands below.

## 2. Quick endpoint check

Test direct context endpoint first:

```powershell
Invoke-RestMethod -Method Get -Uri "http://DEVICE_IP:8081/context"
```

Expected: JSON containing current room context fields such as timestamp, time_source_ntp, occupied, moving, stationary, distance_ft, energy, temperature_f, and pressure_inhg.

Test occupancy history endpoint:

```powershell
Invoke-RestMethod -Method Get -Uri "http://DEVICE_IP:8081/occupancy/history"
```

Expected: JSON with depth, count, and entries. History is edge-only and records only occupied state flips.

## 3. MCP JSON-RPC tests

### Initialize

```powershell
Invoke-RestMethod -Method Post -Uri "http://DEVICE_IP:8081/mcp" -ContentType "application/json" -Body '{"jsonrpc":"2.0","id":1,"method":"initialize","params":{}}'
```

Expected: result with protocolVersion, serverInfo, and capabilities.

### List tools

```powershell
Invoke-RestMethod -Method Post -Uri "http://DEVICE_IP:8081/mcp" -ContentType "application/json" -Body '{"jsonrpc":"2.0","id":2,"method":"tools/list","params":{}}'
```

Expected: includes tools named get_area_data, get_environmental_data, get_occupancy_data, get_air_quality_data, and get_occupancy_history.

### Call tool: get_occupancy_history

```powershell
Invoke-RestMethod -Method Post -Uri "http://DEVICE_IP:8081/mcp" -ContentType "application/json" -Body '{"jsonrpc":"2.0","id":7,"method":"tools/call","params":{"name":"get_occupancy_history","arguments":{}}}'
```

Expected: JSON with depth, count, and occupancy transition entries.

### Call tool: get_area_data

```powershell
Invoke-RestMethod -Method Post -Uri "http://DEVICE_IP:8081/mcp" -ContentType "application/json" -Body '{"jsonrpc":"2.0","id":3,"method":"tools/call","params":{"name":"get_area_data","arguments":{}}}'
```

Expected: result with both `content[0].text` and `structuredContent` containing live room context values.

### Call tool: get_environmental_data

```powershell
Invoke-RestMethod -Method Post -Uri "http://DEVICE_IP:8081/mcp" -ContentType "application/json" -Body '{"jsonrpc":"2.0","id":4,"method":"tools/call","params":{"name":"get_environmental_data","arguments":{}}}'
```

Expected: JSON with temperature_f, humidity_rh, pressure_inhg, and sensor_ready.

### Call tool: get_occupancy_data

```powershell
Invoke-RestMethod -Method Post -Uri "http://DEVICE_IP:8081/mcp" -ContentType "application/json" -Body '{"jsonrpc":"2.0","id":5,"method":"tools/call","params":{"name":"get_occupancy_data","arguments":{}}}'
```

Expected: JSON with presence, motion, static, distance_ft, energy, and sensor_ready.

### Call tool: get_air_quality_data

```powershell
Invoke-RestMethod -Method Post -Uri "http://DEVICE_IP:8081/mcp" -ContentType "application/json" -Body '{"jsonrpc":"2.0","id":6,"method":"tools/call","params":{"name":"get_air_quality_data","arguments":{}}}'
```

Expected: JSON with eco2_ppm, tvoc_ppb, and sensor_ready.

### List resources

```powershell
Invoke-RestMethod -Method Post -Uri "http://DEVICE_IP:8081/mcp" -ContentType "application/json" -Body '{"jsonrpc":"2.0","id":8,"method":"resources/list","params":{}}'
```

Expected: includes uri room://context/current and uri room://occupancy/history.

### Read occupancy history resource

```powershell
Invoke-RestMethod -Method Post -Uri "http://DEVICE_IP:8081/mcp" -ContentType "application/json" -Body '{"jsonrpc":"2.0","id":10,"method":"resources/read","params":{"uri":"room://occupancy/history"}}'
```

Expected: result.contents with occupancy history JSON text.

### Read resource

```powershell
Invoke-RestMethod -Method Post -Uri "http://DEVICE_IP:8081/mcp" -ContentType "application/json" -Body '{"jsonrpc":"2.0","id":9,"method":"resources/read","params":{"uri":"room://context/current"}}'
```

Expected: result.contents with current room context JSON text.

### Ping

```powershell
Invoke-RestMethod -Method Post -Uri "http://DEVICE_IP:8081/mcp" -ContentType "application/json" -Body '{"jsonrpc":"2.0","id":11,"method":"ping","params":{}}'
```

Expected: empty result object.

## 4. Optional curl equivalents

```bash
curl -s http://DEVICE_IP:8081/context
curl -s -X POST http://DEVICE_IP:8081/mcp -H "Content-Type: application/json" -d '{"jsonrpc":"2.0","id":1,"method":"initialize","params":{}}'
```

## 5. Troubleshooting

- If you do not see "MCP HTTP ready" in serial logs:
  - Confirm the Wi‑Fi credentials in [config.h](config.h) are valid.
  - Check for "WiFi connect timeout" log.

- If /context fails:
  - Confirm computer and ESP32 are on the same LAN.
  - Confirm port 8081 is not blocked.

- If /context works but /mcp fails:
  - Verify request method is POST.
  - Verify Content-Type is application/json.
  - Verify JSON-RPC body includes method and id.

- If tools/call returns "Tool not found":
  - Use one of these names exactly: get_area_data, get_environmental_data, get_occupancy_data, get_air_quality_data, get_occupancy_history.

## 6. Security note

The project keeps Wi‑Fi, MQTT, and MCP network settings in [config.h](config.h) instead of scattering them throughout the sketch. If this repository is shared, rotate credentials and keep the file out of source control or use a local-only override.

## 7. Tool rename note and alignment checklist

The MCP tool names changed to use a get_ prefix.

- area_data -> get_area_data
- environmental_data -> get_environmental_data
- occupancy_data -> get_occupancy_data
- air_quality_data -> get_air_quality_data
- occupancy_history -> get_occupancy_history

When MCP tool names or descriptions change, keep these files aligned:

- AI_Occupancy_Sensor.ino: tools/list entries and tools/call name routing.
- MCP-Test.ps1: tools/call request names.
- MCP-Testing.md: expected tool names and request examples.
- README.md: MCP tool contract summary.
- AI_Occupancy_Sensor.md: MCP tool architecture and examples.

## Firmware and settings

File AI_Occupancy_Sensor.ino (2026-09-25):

/*
  AI Occupancy Sensor
  ESP32-C6 + C4002 mmWave Sensor + ENS160 + BME280
  Monitors motion, presence, room occupancy, and air quality.
  Includes WiFi connectivity, web server, MCP, and MQTT reporting.

  Project: AI Occupancy Sensor
  Author: Bill
  Date: 2026-09-21
*/

#include <Arduino.h>
#include <Wire.h>
#include <WiFi.h>
#include <WebServer.h>
#include <PubSubClient.h>
#include <stdlib.h>
#include <time.h>
#include "config.h"

// Pin assignments for the ESP32-C6 board and connected sensors.
constexpr uint8_t C4002_UART_RX = 17;
constexpr uint8_t C4002_UART_TX = 16;
constexpr uint8_t I2C_SDA = 19;
constexpr uint8_t I2C_SCL = 20;

constexpr HTTPMethod HTTP_METHOD_GET = static_cast<HTTPMethod>(1);
constexpr HTTPMethod HTTP_METHOD_POST = static_cast<HTTPMethod>(3);

// Latest parsed values from the C4002 mmWave occupancy sensor.
struct C4002State {
  bool valid = false;
  uint8_t note_type = 0;
  uint8_t target_state = 0;
  uint16_t distance_cm = 0;
  uint8_t energy = 0;
  bool motion = false;
  bool presence = false;
  uint16_t signal_strength = 0;
};

// Normalized, room-level view of the current sensor readings.
struct SensorSnapshot {
  bool c4002_present = false;
  bool motion_detected = false;
  bool static_presence = false;
  float distance_m = 0.0f;
  int energy_level = 0;
  bool ens160_ready = false;
  float eco2_ppm = 0.0f;
  float tvoc_ppb = 0.0f;
  bool bme280_ready = false;
  float temperature_c = 0.0f;
  float humidity_rh = 0.0f;
  float pressure_hpa = 0.0f;
  uint64_t timestamp_ms = 0;
};

struct RoomContext {
  bool occupied = false;
  bool moving = false;
  bool stationary = false;
  bool air_quality_warning = false;
  bool ventilation_recommended = false;
  float occupancy_duration_s = 0.0f;
  float temperature_c = 0.0f;
  float humidity_rh = 0.0f;
  float eco2_ppm = 0.0f;
  float tvoc_ppb = 0.0f;
};

struct OccupancyHistoryEntry {
  uint64_t timestamp_ms = 0;
  bool time_source_ntp = false;
  bool occupied = false;
  bool moving = false;
  bool stationary = false;
  float distance_ft = 0.0f;
  int energy = 0;
};

constexpr size_t OCCUPANCY_HISTORY_DEPTH = 10;

// Driver for the DFRobot C4002 mmWave sensor.
// It wraps the UART packet framing, command payloads, and notification parsing
// required to read motion/presence and distance updates from the sensor.
class C4002Driver {
public:
  static constexpr uint8_t FRAME_HEADER_1 = 0xFA;
  static constexpr uint8_t FRAME_HEADER_2 = 0xF5;
  static constexpr uint8_t FRAME_HEADER_3 = 0xAA;
  static constexpr uint8_t FRAME_HEADER_4 = 0xA5;
  static constexpr uint8_t FRAME_TYPE_WRITE_REQUEST = 0x00;
  static constexpr uint8_t FRAME_TYPE_READ_REQUEST = 0x01;
  static constexpr uint8_t FRAME_TYPE_NOTIFICATION = 0x04;
  static constexpr uint8_t FRAME_TYPE_READ_RESPONSE = 0x03;
  static constexpr uint8_t CMD_SET_LED_MODE = 0xA1;
  static constexpr uint8_t CMD_CONFIG_OUT_MODE = 0xA0;
  static constexpr uint8_t CMD_GET_AND_SET_RESOLUTION_MODE = 0x66;
  static constexpr uint8_t CMD_SET_REPORT_PERIOD = 0x83;
  static constexpr uint8_t CMD_SET_LIGHT_THRESHOLD = 0x88;
  static constexpr uint8_t CMD_SET_DETECT_RANGE = 0x86;
  static constexpr uint8_t CMD_SET_DISTANCE_DOOR = 0x62;
  static constexpr uint8_t CMD_TARGET_DISAPPEAR_DELAY = 0x84;
  static constexpr uint8_t SUCCEED = 0x01;
  static constexpr uint8_t NO_TARGET = 0;
  static constexpr uint8_t PRESENCE = 1;
  static constexpr uint8_t MOTION = 2;

  enum LedMode : uint8_t {
    LED_OFF = 0x00,
    LED_ON = 0x01,
    LED_KEEP = 0xFF,
  };

  enum ResolutionMode : uint8_t {
    RESOLUTION_80CM = 0x00,
    RESOLUTION_20CM = 0x01,
  };

  enum OutPinMode : uint8_t {
    OUT_PIN_MODE1 = 0x01,
    OUT_PIN_MODE2 = 0x02,
    OUT_PIN_MODE3 = 0x03,
  };

  struct Diagnostics {
    uint32_t packets_read = 0;
    uint32_t notifications_seen = 0;
    uint32_t result_notes_parsed = 0;
    uint32_t calibration_notes_seen = 0;
    uint32_t rejected_bad_len = 0;
    uint32_t rejected_bad_resp = 0;
    uint32_t rejected_unknown_note = 0;
  };

  // Initialize the UART connection to the C4002 sensor and store the serial settings.
  bool begin(HardwareSerial &serial, uint8_t rxPin, uint8_t txPin, uint32_t baudRate) {
    serial_ = &serial;
    rxPin_ = rxPin;
    txPin_ = txPin;
    baudRate_ = baudRate;
    serial_->begin(baudRate_, SERIAL_8N1, rxPin_, txPin_);
    delay(50);
    return true;
  }

  // Reset the C4002 to a known-good configuration after a stale or invalid reading.
  bool reinitialize() {
    if (serial_ == nullptr) {
      return false;
    }

    serial_->flush();
    serial_->end();
    delay(150);
    serial_->begin(baudRate_, SERIAL_8N1, rxPin_, txPin_);
    delay(250);

    const uint8_t gateState15[15] = {
      SUCCEED, SUCCEED, SUCCEED, SUCCEED, SUCCEED,
      SUCCEED, SUCCEED, SUCCEED, SUCCEED, SUCCEED,
      SUCCEED, SUCCEED, SUCCEED, SUCCEED, SUCCEED,
    };

    bool ok = true;
    ok = setRunLedState(LED_ON) && ok;
    ok = setOutLedState(LED_ON) && ok;
    ok = setResolutionMode(RESOLUTION_80CM) && ok;
    ok = setOutPinMode(OUT_PIN_MODE3) && ok;
    ok = setLightThresh(0.0f) && ok;
    ok = configureGate(0x00, gateState15, 15) && ok;
    ok = configureGate(0x01, gateState15, 15) && ok;
    ok = setTargetDisappearDelay(60) && ok;
    ok = setDetectRange(0, 1100) && ok;
    ok = setReportPeriod(50) && ok;

    return ok;
  }

  // Detect a sensor state that looks like a reset or invalid all-zero packet instead of a real reading.
  static bool isZeroedState(const C4002State &state) {
    return state.valid && !state.motion && !state.presence && state.distance_cm == 0 && state.energy == 0;
  }

  // Configure how often the C4002 emits report frames to the UART bus.
  bool setReportPeriod(uint8_t period) {
    uint8_t payload[5] = {CMD_SET_REPORT_PERIOD, 0x00, 0x05, 0x00, period};
    return sendCommand(payload, sizeof(payload), FRAME_TYPE_WRITE_REQUEST);
  }

  // Set the C4002 ranging resolution for the configured detection distance window.
  bool setResolutionMode(ResolutionMode mode) {
    uint8_t payload[5] = {CMD_GET_AND_SET_RESOLUTION_MODE, 0x00, 0x05, 0x00, uint8_t(mode)};
    return sendCommand(payload, sizeof(payload), FRAME_TYPE_WRITE_REQUEST);
  }

  // Turn the run LED on or off to indicate the sensor is active or idle.
  bool setRunLedState(LedMode mode) {
    uint8_t payload[6] = {CMD_SET_LED_MODE, 0x00, 0x06, 0x00, uint8_t(mode), LED_KEEP};
    return sendCommand(payload, sizeof(payload), FRAME_TYPE_WRITE_REQUEST);
  }

  // Set the output LED state used by the sensor's reporting behavior.
  bool setOutLedState(LedMode mode) {
    uint8_t payload[6] = {CMD_SET_LED_MODE, 0x00, 0x06, 0x00, LED_KEEP, uint8_t(mode)};
    return sendCommand(payload, sizeof(payload), FRAME_TYPE_WRITE_REQUEST);
  }

  // Configure which output pin mode the C4002 uses for target events.
  bool setOutPinMode(OutPinMode mode) {
    uint8_t payload[5] = {CMD_CONFIG_OUT_MODE, 0x00, 0x05, 0x00, uint8_t(mode)};
    return sendCommand(payload, sizeof(payload), FRAME_TYPE_WRITE_REQUEST);
  }

  // Set the ambient-light threshold used by the C4002 for motion processing.
  bool setLightThresh(float thresholdLux) {
    const uint16_t threshold = uint16_t(thresholdLux * 10.0f);
    uint8_t payload[6] = {
      CMD_SET_LIGHT_THRESHOLD,
      0x00,
      0x06,
      0x00,
      uint8_t(threshold & 0xFF),
      uint8_t((threshold >> 8) & 0xFF),
    };
    return sendCommand(payload, sizeof(payload), FRAME_TYPE_WRITE_REQUEST);
  }

  // Set how long a target remains considered present after it disappears from the sensor field.
  bool setTargetDisappearDelay(uint16_t seconds) {
    uint8_t payload[6] = {
      CMD_TARGET_DISAPPEAR_DELAY,
      0x00,
      0x06,
      0x00,
      uint8_t(seconds & 0xFF),
      uint8_t((seconds >> 8) & 0xFF),
    };
    return sendCommand(payload, sizeof(payload), FRAME_TYPE_WRITE_REQUEST);
  }

  // Configure the distance gate array used for motion and presence detection windows.
  bool configureGate(uint8_t gateType, const uint8_t *gateData, size_t gateCount) {
    if (gateData == nullptr || gateCount == 0 || gateCount > 25) {
      return false;
    }

    uint8_t payload[32] = {0};
    const uint16_t dataLen = uint16_t(5 + gateCount);
    payload[0] = CMD_SET_DISTANCE_DOOR;
    payload[1] = 0x00;
    payload[2] = uint8_t(dataLen & 0xFF);
    payload[3] = uint8_t((dataLen >> 8) & 0xFF);
    payload[4] = gateType;

    for (size_t i = 0; i < gateCount; ++i) {
      payload[5 + i] = gateData[i];
    }

    return sendCommand(payload, dataLen, FRAME_TYPE_WRITE_REQUEST);
  }

  // Configure the target detection range for the C4002 in centimeters.
  bool setDetectRange(uint16_t closestCm, uint16_t farthestCm) {
    if (closestCm > farthestCm || farthestCm > 1100) {
      return false;
    }

    uint8_t payload[8] = {
      CMD_SET_DETECT_RANGE,
      0x00,
      0x08, 0x00,
      uint8_t(closestCm & 0xFF),
      uint8_t((closestCm >> 8) & 0xFF),
      uint8_t(farthestCm & 0xFF),
      uint8_t((farthestCm >> 8) & 0xFF)
    };
    return sendCommand(payload, sizeof(payload), FRAME_TYPE_WRITE_REQUEST);
  }

  // Wait for the next valid C4002 notification frame and decode it into a normalized sensor state.
  bool waitForNotification(C4002State &state, uint32_t timeoutMs) {
    const uint32_t startMs = millis();
    while ((millis() - startMs) < timeoutMs) {
      uint8_t packet[96] = {0};
      size_t actualLen = 0;
      if (readPacket(packet, sizeof(packet), actualLen, 30)) {
        diagnostics_.packets_read++;
        if (parseNotification(packet, actualLen, state)) {
          return true;
        }
      }
    }
    return false;
  }

  // Return the current packet and parsing diagnostics for debugging UART health.
  Diagnostics diagnostics() const {
    return diagnostics_;
  }

private:
  HardwareSerial *serial_ = nullptr;
  uint8_t rxPin_ = 18;
  uint8_t txPin_ = 17;
  uint32_t baudRate_ = 115200;
  Diagnostics diagnostics_ = {};

  // Build and send a framed write/read request to the C4002 and wait for the acknowledgement response.
  bool sendCommand(const uint8_t *payload, size_t payloadLen, uint8_t frameType) {
    if (serial_ == nullptr || payload == nullptr || payloadLen == 0) {
      return false;
    }

    uint8_t packet[32] = {0};
    const uint16_t totalLen = static_cast<uint16_t>(payloadLen + 10);
    packet[0] = FRAME_HEADER_1;
    packet[1] = FRAME_HEADER_2;
    packet[2] = FRAME_HEADER_3;
    packet[3] = FRAME_HEADER_4;
    packet[4] = uint8_t(totalLen & 0xFF);
    packet[5] = uint8_t((totalLen >> 8) & 0xFF);
    packet[6] = 0x00;
    packet[7] = frameType;

    for (size_t i = 0; i < payloadLen; ++i) {
      packet[8 + i] = payload[i];
    }

    const uint16_t sum = checksum(packet, 8 + payloadLen);
    packet[8 + payloadLen] = uint8_t(sum & 0xFF);
    packet[9 + payloadLen] = uint8_t((sum >> 8) & 0xFF);

    serial_->write(packet, totalLen);
    return waitForAck(200);
  }

  // Wait for the C4002 to acknowledge a write command before continuing.
  bool waitForAck(uint32_t timeoutMs) {
    const uint32_t startMs = millis();
    while ((millis() - startMs) < timeoutMs) {
      uint8_t packet[96] = {0};
      size_t actualLen = 0;
      if (!readPacket(packet, sizeof(packet), actualLen, 40)) {
        continue;
      }

      if (actualLen < 10) {
        continue;
      }

      // Notifications can arrive at any time; keep waiting for the write/read response frame.
      if (packet[7] == FRAME_TYPE_NOTIFICATION) {
        continue;
      }

      return packet[9] == SUCCEED;
    }

    return false;
  }

  // Read a raw UART packet from the sensor, skipping malformed frames until a valid one is found.
  bool readPacket(uint8_t *buffer, size_t bufferLen, size_t &actualLen, uint32_t timeoutMs) {
    if (buffer == nullptr || bufferLen == 0 || serial_ == nullptr) {
      return false;
    }

    const uint32_t startMs = millis();
    actualLen = 0;

    while ((millis() - startMs) < timeoutMs) {
      while (serial_->available() >= 8) {
        uint8_t header[8] = {0};
        for (size_t i = 0; i < 8; ++i) {
          int value = serial_->read();
          if (value < 0) {
            break;
          }
          header[i] = uint8_t(value);
        }

        if (header[0] != FRAME_HEADER_1 || header[1] != FRAME_HEADER_2 ||
            header[2] != FRAME_HEADER_3 || header[3] != FRAME_HEADER_4) {
          continue;
        }

        const uint16_t packetLen = uint16_t(header[4] | (header[5] << 8));
        if (packetLen < 10 || packetLen > bufferLen) {
          // Ignore malformed length and keep searching for a valid frame header.
          continue;
        }

        for (size_t i = 0; i < 8; ++i) {
          buffer[i] = header[i];
        }

        size_t remaining = packetLen - 8;
        size_t offset = 8;
        while (remaining > 0 && (millis() - startMs) < timeoutMs) {
          if (serial_->available() == 0) {
            delay(1);
            continue;
          }

          int value = serial_->read();
          if (value < 0) {
            continue;
          }

          buffer[offset++] = uint8_t(value);
          --remaining;
        }

        if (remaining == 0) {
          actualLen = packetLen;
          return true;
        }
      }
      delay(1);
    }

    return actualLen > 0;
  }

  // Decode a C4002 notification frame into motion, presence, distance, and energy values.
  bool parseNotification(const uint8_t *packet, size_t packetLen, C4002State &state) {
    if (packet == nullptr || packetLen < 12) {
      return false;
    }

    if (packet[0] != FRAME_HEADER_1 || packet[1] != FRAME_HEADER_2 ||
        packet[2] != FRAME_HEADER_3 || packet[3] != FRAME_HEADER_4) {
      return false;
    }

    const uint16_t declaredLen = uint16_t(packet[4] | (packet[5] << 8));
    if (declaredLen != packetLen) {
      return false;
    }

    const uint8_t msgType = packet[7];
    if (msgType != FRAME_TYPE_NOTIFICATION) {
      return false;
    }

    diagnostics_.notifications_seen++;

    const uint8_t noteCmd = packet[8];
    const uint8_t respCode = packet[9];
    const uint16_t dataLen = uint16_t(packet[10] | (packet[11] << 8));

    // C4002 notification payload uses a 4-byte data header (cmd, resp, len lo/hi).
    if (packetLen < (size_t(dataLen) + 10)) {
      diagnostics_.rejected_bad_len++;
      return false;
    }

    if (respCode != SUCCEED) {
      diagnostics_.rejected_bad_resp++;
      return false;
    }

    if (noteCmd == 0x03) {
      diagnostics_.calibration_notes_seen++;
      return false;
    }

    if (noteCmd != 0x60 || dataLen < 22) {
      diagnostics_.rejected_unknown_note++;
      return false;
    }

    const uint8_t *data = &packet[12];

    state.valid = true;
    state.note_type = noteCmd;
    state.target_state = data[0];
    state.distance_cm = uint16_t(data[9] | (data[10] << 8));
    state.energy = data[16];
    state.motion = (state.target_state == MOTION);
    state.presence = (state.target_state == PRESENCE || state.target_state == MOTION);
    diagnostics_.result_notes_parsed++;

    return true;
  }

  // Compute the 16-bit checksum used by the C4002 UART protocol.
  uint16_t checksum(const uint8_t *data, size_t len) const {
    uint32_t sum = 0;
    for (size_t i = 0; i < len; ++i) {
      sum += data[i];
    }
    return uint16_t(sum & 0xFFFF);
  }
};

class Ens160Driver {
public:
  // Initialize the ENS160 sensor, verify the device ID, and enable the measurement mode.
  bool begin() {
    uint8_t partId[2] = {0};
    if (!readRegister(0x00, partId, sizeof(partId))) {
      return false;
    }

    if (!writeRegister(0x10, 0x02)) {
      return false;
    }

    delay(50);
    initialized_ = true;
    return true;
  }

  // Read the latest eCO2, TVOC, and AQI values from the ENS160 sensor.
  bool read(uint16_t &eco2, uint16_t &tvoc, uint8_t &aqi) {
    if (!initialized_) {
      return false;
    }

    uint8_t data[6] = {0};
    if (!readRegister(0x20, data, sizeof(data))) {
      return false;
    }

    aqi = data[1];
    tvoc = uint16_t(data[2] | (uint16_t(data[3]) << 8));
    eco2 = uint16_t(data[4] | (uint16_t(data[5]) << 8));
    return true;
  }

private:
  bool initialized_ = false;

  bool readRegister(uint8_t reg, uint8_t *data, size_t len) {
    if (data == nullptr || len == 0) {
      return false;
    }

    Wire.beginTransmission(0x53);
    Wire.write(reg);
    if (Wire.endTransmission(false) != 0) {
      return false;
    }

    const uint8_t bytesRead = Wire.requestFrom(0x53, len);
    if (bytesRead != len) {
      return false;
    }

    for (uint8_t i = 0; i < len && Wire.available(); ++i) {
      data[i] = Wire.read();
    }

    return true;
  }

  // Write a single register value to the ENS160 sensor over I2C.
  bool writeRegister(uint8_t reg, uint8_t value) {
    Wire.beginTransmission(0x53);
    Wire.write(reg);
    Wire.write(value);
    return Wire.endTransmission(true) == 0;
  }
};

class Bme280Driver {
public:
  // Initialize the BME280, verify the device ID, and configure the measurement mode.
  bool begin() {
    uint8_t chipId = 0;
    if (!readRegister(0xD0, &chipId, 1) || chipId != 0x60) {
      return false;
    }

    if (!readCalibration()) {
      return false;
    }

    if (!writeRegister(0xE0, 0xB6)) {
      return false;
    }

    delay(5);

    if (!writeRegister(0xF2, 0x01)) {
      return false;
    }

    if (!writeRegister(0xF5, 0x00)) {
      return false;
    }

    if (!writeRegister(0xF4, 0x27)) {
      return false;
    }

    initialized_ = true;
    return true;
  }

  // Read compensation-corrected temperature, humidity, and pressure values from the BME280.
  bool read(float &temperatureC, float &humidityRH, float &pressureHpa) {
    if (!initialized_) {
      return false;
    }

    uint8_t data[8] = {0};
    if (!readRegister(0xF7, data, sizeof(data))) {
      return false;
    }

    const int32_t rawPressure =
      (int32_t(data[0]) << 12) |
      (int32_t(data[1]) << 4) |
      (int32_t(data[2]) >> 4);
    const int32_t rawTemperature =
      (int32_t(data[3]) << 12) |
      (int32_t(data[4]) << 4) |
      (int32_t(data[5]) >> 4);
    const int32_t rawHumidity =
      (int32_t(data[6]) << 8) |
      int32_t(data[7]);

    compensate(rawTemperature, rawHumidity, rawPressure, temperatureC, humidityRH, pressureHpa);
    return true;
  }
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
void loop() {
  pollNtpTime();

  // Handle any incoming MCP HTTP requests while the node is running.
  if (mcpHttpEnabled) {
    mcpHttpServer.handleClient();
  }

  // Maintain the MQTT connection and periodically publish the latest room state.

  ensureMqttConnected();
  if (mqttEnabled && mqttClient.connected()) {
    mqttClient.loop();
  }

  C4002State c4002State = {};
  if (c4002Driver.waitForNotification(c4002State, 120)) {
    if (C4002Driver::isZeroedState(c4002State)) {
      Serial.println("C4002 reported all-zero state; reinitializing UART and sensor configuration");
      if (c4002Driver.reinitialize()) {
        lastC4002State = {};
        lastC4002UpdateMs = 0;
      }
    } else {
      lastC4002State = c4002State;
      lastC4002UpdateMs = millis();
    }
  }

  const uint32_t nowMs = millis();
  if ((nowMs - lastPublishMs) < 5000UL) {
    return;
  }
  lastPublishMs = nowMs;

  uint16_t eco2 = 0;
  uint16_t tvoc = 0;
  uint8_t aqi = 0;
  float temperatureC = 0.0f;
  float humidityRH = 0.0f;
  float pressureHpa = 0.0f;
  const float tempOffsetC = TEMP_OFFSET_F * (5.0f / 9.0f);

  snapshot = SensorSnapshot{};
  snapshot.timestamp_ms = currentTimestampMs();

  const bool c4002StateFresh = (lastC4002State.valid && (nowMs - lastC4002UpdateMs) <= 90000UL);
  if (c4002StateFresh) {
    snapshot.c4002_present = lastC4002State.presence;
    snapshot.motion_detected = lastC4002State.motion;
    snapshot.static_presence = lastC4002State.presence && !lastC4002State.motion;
    snapshot.distance_m = float(lastC4002State.distance_cm) / 100.0f;
    snapshot.energy_level = int(lastC4002State.energy);
  } else if (lastC4002State.valid) {
    Serial.printf("C4002 stale for %lu ms; reinitializing\n",
                  static_cast<unsigned long>(nowMs - lastC4002UpdateMs));
    if (c4002Driver.reinitialize()) {
      lastC4002State = {};
      lastC4002UpdateMs = 0;
    }
  }

  if (ens160Driver.read(eco2, tvoc, aqi)) {
    snapshot.ens160_ready = true;
    snapshot.eco2_ppm = float(eco2);
    snapshot.tvoc_ppb = float(tvoc);
  }

  if (bme280Driver.read(temperatureC, humidityRH, pressureHpa)) {
    snapshot.bme280_ready = true;
    snapshot.temperature_c = temperatureC + tempOffsetC;
    snapshot.humidity_rh = humidityRH + HUMIDITY_OFFSET_RH;
    if (snapshot.humidity_rh < 0.0f) {
      snapshot.humidity_rh = 0.0f;
    } else if (snapshot.humidity_rh > 100.0f) {
      snapshot.humidity_rh = 100.0f;
    }
    snapshot.pressure_hpa = pressureHpa;
  }

  contextEngine.update(snapshot);
  const RoomContext room = contextEngine.snapshot();
  recordOccupancyHistory(snapshot, room);

  sampleCount++;
  const String sampleTimeText = buildSampleTimeText(snapshot, ntpTimeAvailable);
  Serial.printf("\n--- sample %lu t=%s (%s) ---\n",
                static_cast<unsigned long>(sampleCount),
                sampleTimeText.c_str(),
                ntpTimeAvailable ? "ntp" : "uptime");

  Serial.printf("occupied=%d moving=%d stationary=%d vent=%d\n",
                room.occupied,
                room.moving,
                room.stationary,
                room.ventilation_recommended);

  printSensorSnapshot(snapshot);
  publishMqttState();
}

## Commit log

2026-09-20 Initial commit for the project
    [Case3_back.stl, Case3_front.stl, Case3_middle.stl]
2026-09-23 Update occupancy sensor documentation
